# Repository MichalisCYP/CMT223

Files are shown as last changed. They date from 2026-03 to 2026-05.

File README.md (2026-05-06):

# FocusFlow: Distributed IoT Focus-Assist System

FocusFlow is a modular, distributed IoT system designed to enhance productivity using the Pomodoro technique, environmental monitoring, and computer vision. It features a Raspberry Pi "Fog Hub", an Arduino sensor node, and a modern web dashboard for real-time visualization and AI-powered session reporting.

---

## Key MVP Features

- **Session Management**: Automatic 25-minute focus and 5-minute break timers with start/pause/resume/stop controls via hardware buttons.
- **Environmental Monitoring**: Real-time tracking of light, sound, motion, temperature, and humidity.
- **Focus Estimation**: A heuristic-based focus score (0-100) calculated from environmental conditions.
- **Display Integration**: Grove-LCD (RGB) for environment data and Grove-OLED for session countdowns and focus scores.
- **Data Persistence**: Local SQLite database for offline-first reliability.
- **Cloud Synchronization**: Background publishing of telemetry and session events to AWS IoT Core.
- **Web Dashboard**: React/Vite-based interface with live status updates, historical charts, and AI-summarized focus reports.

---

## System Organisation & Data Flow

FocusFlow follows a "Fog Computing" architecture where data is processed locally at the edge for immediate feedback, while critical events are synced to the cloud for long-term analytics.

```mermaid
graph LR
    subgraph "Edge (Arduino)"
        A[Sensors] --> B[Arduino Firmware]
    end

    subgraph "Fog Hub (Raspberry Pi)"
        B -- "USB Serial (JSON)" --> C[Ingest Worker]
        C --> D[Shared State]
        E[Local Env Worker] --> D
        D --> F[Focus Worker]
        D --> G[Session Worker]
        F --> H[SQLite Repo]
        G --> H
        D --> I[Display Worker]
        I --> J[LCD / OLED]
    end

    subgraph "Vision Node (Raspberry Pi 2)"
        K[Camera] --> L[CV Processor]
    end

    subgraph "Cloud & Client"
        H -- "MQTT" --> M[AWS IoT Core]
        L -- "HTTPS/MQTT" --> M
        M -- "WebSockets" --> N[Web Dashboard]
        D -- "Local API" --> N
        O[Groq AI] -- "Analysis" --> N
    end
```

---

## Folder and File Structure

### Root Directory
- `arduino/`: Firmware for the Arduino-based sensor node.
- `raspberry/`: Core "Fog Node" implementation for the primary Raspberry Pi.
- `raspberry-2/`: Computer Vision (CV) processing node for the secondary Raspberry Pi.
- `FocusFlowDashboard/`: A React-based web dashboard for real-time visualization and analytics.
- `docs/`: Comprehensive project documentation following university SDLC standards.
- `iot-lab-book-master/`: Reference implementations and lab exercises used as a foundation.
- `requirements.txt`: Global Python dependencies.
- `SETUP.md`: (Deprecated) Integrated into this README.

### arduino/main/
The firmware responsible for local sensor polling and data transmission.
- `main.ino`: Primary entry point and setup/loop logic.
- `config.h`: Centralized pin definitions, thresholds, and timing constants.
- `environment_sensors.h`: Logic for reading Light, Sound, PIR, and DHT sensors.
- `payload_formatter.h`: Handles JSON serialization for data transmission to the Pi.
- `usbserial_transport.h`: Manages serial communication over USB.

### raspberry/
The "Brain" of the system, handling session logic, data persistence, and display updates.
- `main.py`: Entry point for the fog node.
- `fog/`: Core logic package containing multi-threaded workers for ingestion, session management, and focus calculation.
- `focusflow_mvp.db`: Local SQLite database storing telemetry and session events.

---

## Setup Instructions

### 1. Prerequisites
- **AWS Account**: Access to AWS IoT Core for cloud communication.
- **Python 3.9+**: Installed on both Raspberry Pi units.
- **Node.js 18+**: Installed for the Dashboard.
- **Arduino IDE**: For flashing the edge device firmware.
- **Hardware**: Arduino board, Raspberry Pi (Hub), Raspberry Pi (CV Node).

### 2. Hardware Wiring (Arduino)
Connect sensors to the specified pins as defined in `arduino/main/config.h`:
- **Light Sensor**: Analog Pin `A3`
- **Sound Sensor**: Analog Pin `A0`
- **PIR Motion Sensor**: Digital Pin `D2`
- **Button**: Digital Pin `D3` (Momentary, active LOW)
- **Ultrasonic Ranger**: Digital Pin `D7`
- **DHT Sensor**: Digital Pin `D4` (connected via GrovePi or directly)

### 3. Installation
#### Arduino Edge Device
1. Open `arduino/main/main.ino` in the Arduino IDE.
2. Install the **DHT sensor library** (by Adafruit) via the Library Manager.
3. Connect your Arduino and flash the code.

#### Raspberry Pi (Central Hub)
1. Navigate to `raspberry/` and install system dependencies:
   ```bash
   curl -kL https://get.pimoroni.com/grovepi | bash
   pip3 install -r requirements.txt
   ```
2. Run the initialization script:
   ```bash
   chmod +x start.sh && ./start.sh
   ```

#### FocusFlow Dashboard
1. Navigate to `FocusFlowDashboard/` and install dependencies:
   ```bash
   npm install
   ```

### 3. Configuration
- **AWS IoT**: Place your device certificates (`cert.pem`, `private.key`) in the `raspberry/` and `raspberry-2/` folders as appropriate.
- **Environment**: Copy `.env.example` to `.env` in the `FocusFlowDashboard/` directory and provide your `GROQ_API_KEY`.

---

## 🚀 Running the Project

### 1. Start the Hub & Edge
Plug the Arduino into the Central Pi via USB, then start the Fog service:
```bash
cd raspberry
python3 main.py
```

### 2. Start the CV Node
Run the vision script on the camera-equipped Pi:
```bash
cd raspberry-2
python3 basicCV.py --headless --hub-url http://<HUB_IP>:8787/api/peer-ingest
```

### 3. Start the Dashboard
Launch both the Vite frontend and Express backend:
```bash
cd FocusFlowDashboard
npm run dev:all
```
Access the UI at `http://localhost:5173`.

---

## Telemetry & Communication

### Arduino → Hub (JSON over Serial)
The Arduino node sends telemetry every 1 second in the following format:
```json
{ "v": 1, "light": 412, "sound": 275, "move": 1, "button": 0 }
```
It also sends discrete events for button interactions:
```json
{"v": 1, "btn_event": "SHORT"}
{"v": 1, "btn_event": "LONG"}
```

### Hub → Cloud (MQTT)
The Hub publishes data to AWS IoT Core on the following topics:
- `focusflow/environment`: Real-time sensor readings.
- `focusflow/session`: Session state changes (started, paused, stopped).
- `focusflow/focus`: Calculated focus scores and reason codes.

---

## Third-Party Software and Frameworks

| Software / Framework | Purpose | Documentation |
| :--- | :--- | :--- |
| **Arduino** | Hardware abstraction and sensor firmware platform | [arduino.cc](https://www.arduino.cc/) |
| **AWS IoT Core** | Managed cloud service for MQTT-based device sync | [aws.amazon.com/iot](https://aws.amazon.com/iot-core/) |
| **React** | Frontend library for the Dashboard UI | [react.dev](https://react.dev/) |
| **Vite** | Next-generation frontend tooling and dev server | [vitejs.dev](https://vitejs.dev/) |
| **Express** | Minimalist web framework for the backend API | [expressjs.com](https://expressjs.com/) |
| **OpenCV** | Open-source computer vision library | [opencv.org](https://opencv.org/) |
| **MediaPipe** | ML framework for face and gesture tracking | [mediapipe.dev](https://mediapipe.dev/) |
| **Groq** | High-speed AI inference for session reporting | [groq.com](https://groq.com/) |
| **SQLite** | Self-contained, serverless database engine | [sqlite.org](https://www.sqlite.org/) |

---

## Code Documentation

- **In-line Comments**: All Python and Arduino source files follow standard PEP8/Google style guides with descriptive comments.
- **Project Docs**: Detailed architectural designs, requirements, and implementation plans are located in the `docs/` directory.
- **Reference Lab Code**: This project builds upon concepts from the `iot-lab-book-master/` reference material:
    - **LAB 02**: DHT sensor reading patterns (used in `LocalEnvironmentWorker`).
    - **LAB 04/06**: MQTT cloud and Full Stack patterns (used in AWS Publisher).
    - **LAB 09**: Pi concurrency and worker orchestration (used in `fog/main.py`).

---

## Troubleshooting

- **Serial Device Errors**: If the Hub cannot connect to the Arduino, ensure the user has permissions for `/dev/ttyACM0` (`sudo usermod -a -G dialout $USER`).
- **Grove Hardware Not Found**: Verify that I2C is enabled in `raspi-config` and that the GrovePi board is correctly seated.
- **AWS Sync Failures**: Check that the system clock is synchronized (NTP) and that certificates are correctly named in `raspberry/main.py`.
- **Dashboard API Offline**: Ensure port `8787` is not blocked by a firewall and that `concurrently` is installed.

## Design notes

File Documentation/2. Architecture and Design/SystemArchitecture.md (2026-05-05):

# System Architecture

The FocusFlow system follows a tiered IoT architecture (Edge, Fog, Cloud) designed for real-time focus monitoring and productivity enhancement.

## High-Level Diagram

```mermaid
%%{init: {"flowchart": {"defaultRenderer": "elk", "htmlLabels": true}}}%%
flowchart TB
    %% LAYOUT CONTROL
    subgraph EDGE["Edge Layer: Sensing & Biometrics"]
        direction LR
        subgraph ARD["Arduino Sensor Node"]
            direction TB
            MCU["Atmega328P"]
            S1["Grove Light A3"]
            S2["Grove Sound A0"]
            S3["Grove DHT D5"]
            S4["Grove PIR D2"]
            S5["Grove Ultrasonic D6"]
            A1["LED Buttons D3/D7"]
        end
        subgraph CV["Raspberry Pi CV Node"]
            direction TB
            CAM["CSI/USB Camera"]
            PROC["OpenCV/MediaPipe"]
            SEC1["MQTT/TLS"]
        end
    end

    subgraph FOG["Fog Layer: Local Intelligence & Hub"]
        direction LR
        HUB["Pi Hub Controller"]
        DB1[("SQLite")]
        ALGO["Focus Analysis Worker"]
        INGEST["ArduinoIngestWorker"]
        GROVE["GroveWorker"]
        SESSION["SessionWorker"]
        DIS["DisplayWorker"]
        PUB["AwsIotPublisherWorker"]
        RPC["RpcWorker"]
        LCD["Grove LCD I2C"]
        OLED["OLED Display I2C"]
    end

    subgraph CLOUD["Cloud Layer: Aggregation & Services"]
        direction LR
        IOT["AWS IoT Core"]
        API["Cloud Node API"]
        DB2[("Cloud Database")]
        ANL["Cloud Analytics"]
    end

    subgraph CLIENT["Client Layer: User Interface"]
        direction TB
        subgraph DASH["FocusFlow Dashboard"]
            direction TB
            VZN["Visualization Engine"]
            subgraph VIEWS["Interactive Views"]
                direction LR
                LIVE["Live Environment"]
                TRND["Productivity Trends"]
                HIST["Session History"]
            end
        end
    end

    %% CONNECTIONS
    S1 -- Analog --- MCU
    S2 -- Analog --- MCU
    S3 -- Digital --- MCU
    S4 -- Digital --- MCU
    S5 -- Digital --- MCU
    A1 -- GPIO --- MCU

    CAM -- Frames --> PROC
    PROC -- "Payload: {facePresent:bool, eyes_detected:bool...}" --> SEC1

    MCU -- "USB Serial / JSON (Payload: {light, sound, move, temp, hum, distance_cm, button, button2})" --> INGEST
    INGEST -- parsed environment data --> HUB
    HUB -- light, sound, distance, move, temperature --> ALGO
    HUB -- grove button input --> GROVE
    GROVE -- button events --> SESSION
    HUB -- button events --> SESSION
    HUB <--> DB1
    ALGO -. "Inference: focus_score, reasons" .-> DB1

    SESSION -- session state --> LCD
    SESSION -- session state --> OLED
    HUB -- state snapshot --> DIS
    DIS -- "Env Metrics & Focus Score" --> LCD
    DIS -- "Timer & Session State" --> OLED

    HUB -- state snapshot --> RPC
    RPC -- "REST API / HTTP" --> VZN
    API <-- "HTTPS / WebSockets" --> VZN
    API -. "Aggregates: session_history, trends" .-> VZN

    SEC1 -- "MQTT over TLS" --> IOT
    PUB -- "MQTT over TLS" --> IOT
    HUB -- sensor & session data --> PUB
    IOT --> API
    API --> DB2 & ANL
```

## 1. System Components

### Edge Layer

- **Arduino Sensor Node**: A microcontroller-based unit that handles environmental sensing and physical user interaction (buttons).
- **Raspberry Pi CV Node**: A dedicated computer vision unit that processes video streams locally to extract focus-related biometric signals.

### Fog Layer

- **Raspberry Pi Hub**: The "brain" of the local environment. It orchestrates data ingestion, runs the local session manager (Pomodoro logic), and computes the real-time **Focus Score**.
- **Local Storage (SQLite)**: Ensures "local-first" operation, allowing the system to function without an internet connection.

### Cloud Layer

- **AWS IoT Core**: Acts as the secure message broker for device-to-cloud communication.
- **Cloud Node Services**: Handles long-term persistence, cross-session analytics, and serves the user-facing API.

### Client Layer

- **FocusFlow Dashboard**: A modern web application for real-time monitoring, historical review, and system configuration.

---

## 2. Data Types & Collection

| Category | Data Points | Collection Method |
| :--- | :--- | :--- |
| **Environmental** | `light_level`, `sound_level`, `temp`, `humidity`, `movement`, `distance` | Periodic sampling (1Hz - 5Hz) via Arduino  |
| **Biometric** | `face_present`, `looking_away`, `head_pose`, `slouching` | Local CV inference on Pi (2s interval) |
| **Session** | `status` (running/paused), `phase` (work/break), `duration` | Event-driven state transitions in Fog Node |
| **Inference** | `focus_score` (0-100), `focus_reasons`, `confidence` | Computed every 5s by Fog Node workers |

---

## 3. Sensors and Actuators

### Sensors

- **Light Sensor (Grove)**: Measures ambient lighting quality.
- **Sound Sensor (Grove)**: Estimates environmental noise distractions.
- **DHT11 (Grove)**: Monitors room comfort (Temperature/Humidity).
- **PIR Motion (Grove)**: Detects physical presence/movement.
- **Ultrasonic Ranger (Grove)**: Monitors desk distance and posture.
- **Camera (Pi Camera/USB)**: Captures video for local biometric analysis.

### Actuators

- **LED Buttons**: Provide visual feedback for session status (e.g., Glowing during work).
- **Grove LCD (16x2)**: Displays real-time environment metrics (Temperature, Humidity) and the current **Focus Score**.
- **OLED Display (128x64)**: Shows the active **Pomodoro Timer** and current session state (Work/Break/Paused).

---

## 4. Network Protocols & Communication

- **USB Serial (JSON)**: Reliable, low-latency communication between Arduino and Pi Hub.
- **I2C**: High-speed serial bus for local displays (LCD/OLED).
- **MQTT over TLS (MQTTS)**: Industry-standard secure messaging for IoT-to-Cloud telemetry.
- **HTTPS (REST)**: Secure request-response for dashboard-to-cloud configuration.
- **WebSockets (WSS)**: Low-latency, full-duplex communication for real-time dashboard updates.

---

## 5. Data Analytics Processes

### Edge Analytics (Biometrics)

The CV Node uses **Haar Cascades** and **MediaPipe Face Mesh** to process raw video frames. It extracts high-level features (like head yaw/pitch) without sending images to the cloud, ensuring user privacy.

### Fog Analytics (Local Inference)

The Fog Hub runs a **Multi-Factor Scoring Engine** that combines:

1. Environmental noise/light stability.
2. User presence and posture.
3. CV-derived focus signals.
   The engine outputs a normalized **Focus Score (0-100)** used for local alerts and displays.

### Cloud Analytics (Insights)

The Cloud Node aggregates data over days and weeks to identify **Productivity Trends**, such as peak focus times and common distractors. These insights are served via REST APIs to the client dashboard.

### Dashboard Analytics (Visualization)

The FocusFlow Dashboard transforms raw and aggregated data into actionable insights:

1. **Real-time Environment**: Visualizes live telemetry (light, sound, focus score) using WebSockets for immediate feedback.
2. **Trend Analysis**: Utilizes charting libraries (e.g., Recharts) to plot historical trends, allowing users to visualize productivity over time.
3. **Session History**: Processes event-driven data to reconstruct past focus sessions, providing a detailed log of work-break cycles and performance.

---

## 6. Security and Privacy

- **Transport Security**: All network communication (MQTT, HTTPS, WebSockets) is encrypted using **TLS 1.2/1.3**.
- **Device Authentication**: Devices connect to AWS IoT Core using **X.509 Client Certificates**, ensuring only authorized hardware can send data.
- **Local-First Privacy**: CV processing is entirely local. No video or images are stored or transmitted; only anonymous metadata (e.g., `looking_away: true`) leaves the device.
- **Access Control**: The Web Dashboard requires **JWT-based authentication** to access user-specific productivity data.

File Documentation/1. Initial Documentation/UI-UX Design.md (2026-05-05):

# Dashboard UX

## MVP Screens

- Live session
- Session history
- Alerts panel (can live inside main page)

## Live Session (Priority)

Must show:

- session title and state
- timer + current phase
- focus score
- current sensor values
- presence/CV status
- latest alerts
- actions: start, pause, resume, finish, acknowledge

Suggested layout:

- top: timer + focus + state
- middle: sensor cards
- bottom: event feed + controls

## History

Show:

- past sessions
- average focus per session
- simple trend charts (focus/environment)
- break recommendations vs acknowledgements

## UX Rules

- readable at a glance
- no debug noise on main screen
- actionable alerts only
- keep demo path obvious

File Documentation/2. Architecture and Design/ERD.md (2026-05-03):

# Data Model And Storage

## Storage Rules

- SQLite on the hub is the source of truth.
- Write local first, sync later.
- Thread-safe operations using locks for concurrent access.

## Core Tables

- environment_log: raw sensor readings from the environment.
- session_event: session lifecycle and phase tracking events.
- focus_log: computed focus scores and analysis results.

## SQLite Schema

```sql
CREATE TABLE environment_log (
    id INTEGER PRIMARY KEY AUTOINCREMENT,
    ts TEXT NOT NULL,
    light INTEGER,
    sound INTEGER,
    move INTEGER,
    button INTEGER,
    temperature REAL,
    humidity REAL,
    distance_cm INTEGER
);

CREATE TABLE session_event (
    id INTEGER PRIMARY KEY AUTOINCREMENT,
    ts TEXT NOT NULL,
    status TEXT NOT NULL,
    phase TEXT NOT NULL,
    remaining_seconds INTEGER NOT NULL
);

CREATE TABLE focus_log (
    id INTEGER PRIMARY KEY AUTOINCREMENT,
    ts TEXT NOT NULL,
    score INTEGER NOT NULL,
    confidence TEXT NOT NULL,
    reason TEXT NOT NULL
);
```

## Relationships

- environment_log: independent periodic sensor readings.
- session_event: independent session state changes and phase tracking.
- focus_log: independent computed focus analysis results.

## ERD

```mermaid
erDiagram
    ENVIRONMENT_LOG {
        INTEGER id PK
        TEXT ts
        INTEGER light
        INTEGER sound
        INTEGER move
        INTEGER button
        REAL temperature
        REAL humidity
        INTEGER distance_cm
    }

    SESSION_EVENT {
        INTEGER id PK
        TEXT ts
        TEXT status
        TEXT phase
        INTEGER remaining_seconds
    }

    FOCUS_LOG {
        INTEGER id PK
        TEXT ts
        INTEGER score
        TEXT confidence
        TEXT reason
    }
```

## AWS DynamoDB (Computer Vision)

- Table name: `computer_vision`
- Partition key: `device_id` (String)
- Sort key: `timestamp` (String)

Attributes:

- `device_id` (String)
- `timestamp` (String)
- `confidence` (Number or String)
- `eyes_detected` (Number)
- `face_present` (Boolean)
- `head_pose` (String)
- `looking_away` (Boolean)
- `slouching` (Boolean)

Example DynamoDB item (JSON):

```json
{
  "device_id": "device-123",
  "timestamp": "2026-05-03T12:34:56Z",
  "confidence": 0.92,
  "eyes_detected": 2,
  "face_present": true,
  "head_pose": "forward",
  "looking_away": false,
  "slouching": false
}
```

Mermaid ERD addition:

```mermaid
erDiagram
    COMPUTER_VISION {
        TEXT device_id PK
        TEXT timestamp PK
        REAL confidence
        INTEGER eyes_detected
        BOOLEAN face_present
        TEXT head_pose
        BOOLEAN looking_away
        BOOLEAN slouching
    }
```

## Data Access Patterns

- `write_environment()`: Insert periodic sensor readings with full payload.
- `write_session_event()`: Insert session state and phase changes.
- `write_focus()`: Insert computed focus analysis results.
- `latest_environment()`: Retrieve most recent sensor reading.
- `latest_session_event()`: Retrieve most recent session state.
- `latest_focus()`: Retrieve most recent focus analysis.

## Retention Defaults

- environment_log: every 1-5 seconds (managed by application logic).
- session_event: key state transitions throughout session.
- focus_log: every 30 seconds (managed by application logic).

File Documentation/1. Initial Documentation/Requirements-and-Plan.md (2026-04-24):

# Smart IoT Desk Assistant: Unified Requirements and 2-Person Delivery Plan

Deadline: 07/05/2026

This file is the single source of truth for MVP scope, delivery, and ownership.

## 1. Goal

Build a local-first focus assistant that can run a full study session without internet while providing explainable focus feedback and gentle interventions.

## 2. Scope

### 2.1 In Scope (MVP)

- Arduino telemetry: light, sound, PIR motion, temperature/humidity, distance.
- Raspberry Pi hub: ingest data, run session logic, compute focus score, store in SQLite.
- CV signal integration: face presence and looking-away input.
- Dashboard: live status and session history.
- Alerts: buzzer/display prompts with manual acknowledge/override.
- Background sync to AWS IoT Core (non-blocking).

### 2.2 Out Of Scope (MVP)

- Polished mobile app.
- Trained custom ML models.
- Full cloud analytics platform.
- Multi-user profiles.
- Phone detection for enforcement workflows (can be revisited after MVP).

## 3. Functional Requirements

1. Environment Monitoring

- Read light, sound, movement, temperature/humidity, and distance/presence signals.

2. Focus Estimation

- Generate a focus score from available sensor and CV signals.
- Mark confidence when signals are missing.

3. Session Management

- Create, start, pause, resume, and finish sessions.
- Support Pomodoro-style focus and break periods.

4. Interventions

- Trigger buzzer/display prompts from rule thresholds.
- Support manual acknowledge and override.

5. Dashboard

- Show live metrics and active session state.
- Show session history and summary statistics.

6. Cloud Sync

- Persist locally first.
- Retry cloud sync in the background without affecting local flow.

## 4. Non-Functional Requirements

- Works offline for full local session behavior.
- Survives temporary USB serial, CV, or cloud failures.
- Near real-time local dashboard updates (polling every 2 seconds for MVP).
- Maintainable by a 2-person team and demonstrable by 07/05/2026.

## 5. Constraints

- Team size: 2 people.
- Hardware available: 2 Arduinos, 2 Raspberry Pis.
- Raspberry Pi CPU budget is tight when combining CV + messaging + backend.
- AWS IoT Core learning curve is a delivery risk.

## 6. Finalized MVP Decisions

| ID | Decision | Outcome | Rationale |
| ---- | --- | --- | --- |
| D-01 | Temp/humidity sensor location | Arduino edge node | Keep core environment telemetry in one constant edge payload |
| D-02 | Display module | Grove I2C display on Raspberry Pi hub | Easy integration with Raspberry Pi and clear local feedback  |
| D-03 | Button behavior | Single momentary button on Pi hub: short press acknowledge, long press pause/resume | Direct local interaction with fog session manager |
| D-04 | CV node scope | Face presence + looking-away only | Useful signal without over-scoping ML |
| D-05 | CV transport | Local HTTP POST | Fast integration and easy debugging |
| D-06 | Dashboard updates | HTTP polling every 2 seconds | Reliable for MVP without WebSocket complexity |
| D-07 | AWS scope | AWS IoT Core only for MVP | Reduces delivery risk |

## 7. Technical Baseline (Recommended)

| Layer | Recommended Technology | Rationale |
| --- | --- | --- |
| Edge and Hub | Python 3.11, paho-mqtt, OpenCV | Mature Raspberry Pi ecosystem |
| CV Node | MediaPipe Face Mesh (presence and looking-away signals) | Good speed and reliability for MVP |
| Messaging | Mosquitto MQTT broker (local telemetry) | Lightweight and low-latency |
| Backend | FastAPI + SQLite | Fast delivery with zero-config DB  |
| Dashboard | Web dashboard (React or simple server-rendered UI) | Mobile app is out of MVP scope |
| Cloud | AWS IoT Core | Matches MVP cloud boundary |

## 8. Working Assumptions

- The system must continue local session behavior during cloud outage.
- Missing CV data should degrade confidence but not stop scoring.
- One active session at a time is sufficient for MVP.
- Any stretch goals are only attempted after all success criteria in Section 12 are met.

## 9. Two-Person Team Split

Person A: Hardware, Firmware, and CV

- Arduino wiring, firmware, and stable telemetry payloads.
- Hub-side device integration for buzzer, display, button behavior.
- CV runtime setup and local signal posting (presence and looking-away).
- Sensor calibration and hardware troubleshooting.

Person B: Hub Backend, Data, Dashboard, and Cloud Sync

- FastAPI endpoints, session state machine, and focus logic integration.
- SQLite schema, data writes, and session/history queries.
- Live dashboard and session controls.
- Background sync queue to AWS IoT Core.

Shared ownership

- Focus score threshold tuning.
- End-to-end integration, testing, demo script, and final report.

## 10. Delivery Plan to 07/05/2026

Delivery order:

1. Local MVP first.
2. Add focus and interventions.
3. Add CV integration.
4. Add cloud sync last.

### Phase 1: Foundation and Local MVP (22/03-04/04)

Outcomes:

- Stable Arduino telemetry into hub.
- SQLite writes and basic API routes running.
- Session create/start/finish and active dashboard view.

Tasks:

- Lock pin map and payload format.
- Implement local DB schema and ingest pipeline.
- Build initial dashboard page for live readings.

### Phase 2: Focus and Interventions (05/04-18/04)

Outcomes:

- Heuristic focus score running end-to-end.
- Buzzer/display prompts with acknowledge and override.

Tasks:

- Implement scoring thresholds and confidence output.
- Wire button short press (ack) and long press (pause/resume).
- Show intervention events in dashboard timeline.

### Phase 3: CV Integration and Hardening (19/04-30/04)

Outcomes:

- CV node sends face presence and looking-away signals to hub.
- Focus engine consumes CV when available and degrades gracefully when missing.

Tasks:

- Set up CV runtime and post compact payloads via local HTTP POST.
- Tune score weights and CPU usage on Raspberry Pi.
- Validate dashboard responsiveness with 2-second polling.

### Phase 4: Cloud Sync, Testing, and Demo Freeze (01/05-07/05)

Outcomes:

- Background sync to AWS IoT Core without blocking local flow.
- Integration tests and demo checklist completed.
- Final report artifacts updated.

Tasks:

- Implement sync queue worker and retry/backoff behavior.
- Run offline, dropout, and recovery test scenarios.
- Freeze demo build and finalize documentation.

## 11. Milestones

| Date Target | Milestone |
| --- | --- |
| 28/03/2026  | Sensors publish telemetry and backend stores data |
| 04/04/2026  | Session state and live dashboard are operational |
| 12/04/2026  | Focus score and interventions run end-to-end |
| 24/04/2026  | CV signals integrated and reflected in score/confidence |
| 03/05/2026  | AWS IoT Core background sync validated |
| 07/05/2026  | Final demo-ready system and report handoff |

## 12. Success Criteria

1. One full local session runs end-to-end.
2. Data persists in SQLite.
3. Focus status is visible and explainable.
4. At least one intervention triggers correctly.
5. System still works with internet disabled.

## 13. Risks and Scope Controls

Primary risks:

- Pi performance bottlenecks under combined CV and telemetry load.
- Accuracy degradation under poor lighting or glasses.
- Privacy and ethics concerns for camera-based monitoring.

If schedule pressure increases, reduce scope in this order:

1. Keep only face presence CV signal, defer looking-away.
2. Defer cloud summaries and publish only key session events.
3. Replace any LLM summary logic with rule-based templates.

## 14. Academic and Reporting Requirements

- Cite at least two studies linking indoor environment quality to cognitive performance.
- Reference nudge theory and relevant HCI literature for intervention design.
- Include ethics section: consent, camera usage transparency, retention policy.
- Include system architecture diagram and measurable targets (for example alert latency and score responsiveness).

## 15. Change Control

If decisions or scope change, update this file and related architecture/testing documents in the same commit.

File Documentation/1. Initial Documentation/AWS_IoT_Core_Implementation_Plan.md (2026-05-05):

# AWS IoT Core Implementation Plan (FocusFlow)

## 1. Purpose

Implement a cloud node on AWS that receives locally stored data from the Raspberry Pi Fog node, then serves that data to:

- Dashboard (web)

This plan is aligned to the current project architecture and codebase, especially:

- `raspberry/fog/repository.py`
- `raspberry/fog/workers.py`
- `raspberry/fog/config.py`
- `docs/1. Requirements/Requirements-and-Plan.md`
- `docs/2. Architecture and Design/SystemArchitecture.md`

## 2. Current Local State (As-Is)

The Raspberry Pi Fog node already writes data to local SQLite using three tables:

- `environment_log`
- `session_event`
- `focus_log`

Workers already run in background threads for ingest, session state, focus scoring, and display. A cloud sync worker is not yet implemented in the current code.

## 3. Target AWS Architecture (MVP)

### 3.1 Data Flow

1. Fog node writes all data to SQLite first (local-first behavior).
2. New background sync worker reads unsynced rows and publishes to AWS IoT Core over MQTT/TLS.
3. AWS IoT Rules route messages to cloud storage.
4. Cloud API reads cloud storage and serves dashboard queries.

### 3.2 AWS Services

Required for MVP:

- AWS IoT Core (device connectivity, MQTT topics, rules)
- DynamoDB (operational query store for app reads)
- Lambda (rule transform and API handlers)
  -- API Gateway (HTTPS endpoints for dashboard)
- CloudWatch Logs (observability)
- IAM (least-privilege access)

Recommended:

- Amazon Timestream (time-series analytics, optional if DynamoDB-only is sufficient for MVP)
  -- Cognito (user auth for dashboard)

## 4. MQTT Topic and Payload Design

### 4.1 Topic Convention

Use environment-based topic prefix:

- `focusflow/{env}/{site_id}/{device_id}/environment`
- `focusflow/{env}/{site_id}/{device_id}/session`
- `focusflow/{env}/{site_id}/{device_id}/focus`
- `focusflow/{env}/{site_id}/{device_id}/heartbeat`
- `focusflow/{env}/{site_id}/{device_id}/ack` (optional)

Example:

- `focusflow/prod/lab-a/pi-hub-01/environment`

### 4.2 Message Envelope

Every published message should include:

```json
{
  "message_id": "uuid-v4",
  "event_type": "environment|session|focus",
  "occurred_at": "2026-04-21T12:00:00Z",
  "published_at": "2026-04-21T12:00:02Z",
  "device_id": "pi-hub-01",
  "site_id": "lab-a",
  "payload": {
    "...": "table-specific fields"
  }
}
```

Table mapping:

- `environment_log` -> `event_type=environment`
- `session_event` -> `event_type=session`
- `focus_log` -> `event_type=focus`

## 5. Raspberry Pi Changes Required

### 5.1 SQLite Schema Updates

Add sync metadata to support reliable retries:

Option A (recommended): dedicated queue table

```sql
CREATE TABLE IF NOT EXISTS cloud_sync_queue (
  id INTEGER PRIMARY KEY AUTOINCREMENT,
  source_table TEXT NOT NULL,
  source_row_id INTEGER NOT NULL,
  topic TEXT NOT NULL,
  payload_json TEXT NOT NULL,
  status TEXT NOT NULL DEFAULT 'pending',
  retry_count INTEGER NOT NULL DEFAULT 0,
  next_retry_at TEXT,
  last_error TEXT,
  created_at TEXT NOT NULL,
  updated_at TEXT NOT NULL,
  UNIQUE(source_table, source_row_id)
);
```

Option B: add `synced_at` column to each existing table (simpler but less flexible).

Use Option A for clearer retry/backoff and operational visibility.

### 5.2 Repository Layer

Extend `Repository` with methods such as:

- `enqueue_for_cloud(source_table, source_row_id, topic, payload_json)`
- `fetch_pending_batch(limit, now_iso)`
- `mark_synced(queue_id)`
- `mark_retry(queue_id, retry_count, next_retry_at, last_error)`

When writing `environment_log`, `session_event`, and `focus_log`, also enqueue a corresponding cloud message.

### 5.3 New Background Worker

Add `CloudSyncWorker` in `raspberry/fog/workers.py`:

Responsibilities:

- Maintain AWS IoT MQTT connection (TLS cert auth)
- Poll pending queue batch every N seconds
- Publish each message with QoS 1
- Mark success/failure in queue
- Apply exponential backoff with jitter
- Keep running even if internet drops

Backoff suggestion:

- `next_retry = min(base * (2 ^ retry_count), max_backoff) + jitter`
- base: 2s
- max_backoff: 300s

### 5.4 Configuration

Add to `FogConfig` in `raspberry/fog/config.py`:

- `aws_iot_endpoint`
- `aws_iot_port` (8883)
- `aws_iot_client_id`
- `aws_iot_topic_prefix`
- `aws_iot_cert_path`
- `aws_iot_key_path`
- `aws_iot_ca_path`
- `cloud_sync_batch_size` (for example 50)
- `cloud_sync_poll_seconds` (for example 2.0)
- `cloud_sync_enabled` (true/false)

### 5.5 Main Startup Wiring

In `raspberry/fog/main.py`, instantiate and start the new `CloudSyncWorker` with other workers.

Critical behavior:

- If cloud worker fails, local workers continue.
- Never block local session flow due to cloud issues.

## 6. AWS IoT Core Setup Steps (Colleague Checklist)

### 6.1 Device Provisioning

1. Create IoT Thing per Pi hub (for example `pi-hub-01`).
2. Create certificate and keys.
3. Attach IoT policy allowing publish only to project topics.
4. Download cert/key/CA and place securely on Pi.

Policy scope example:

- Allow `iot:Connect` for approved client ID.
- Allow `iot:Publish` to `focusflow/prod/*`.
- Deny wildcard subscribe if not needed.

### 6.2 Topic Rule Routing

Create AWS IoT Rules for each topic family:

- Rule 1: environment topic -> Lambda transform -> DynamoDB table
- Rule 2: session topic -> Lambda transform -> DynamoDB table
- Rule 3: focus topic -> Lambda transform -> DynamoDB table

Alternative: one generic rule with `event_type` branching in Lambda.

### 6.3 Cloud Data Model (DynamoDB)

Create table: `FocusFlowEvents`

- Partition key: `pk` = `SITE#{site_id}#DEVICE#{device_id}`
- Sort key: `sk` = `TS#{occurred_at}#TYPE#{event_type}#ID#{message_id}`
- GSI1 (optional): `event_type` + timestamp for cross-device dashboards

Store original payload and normalized fields for query efficiency.

### 6.4 API Layer for Dashboard

Use API Gateway + Lambda endpoints:

- `GET /api/live/latest?site_id=...&device_id=...`
- `GET /api/sessions/recent?site_id=...&device_id=...`
- `GET /api/focus/trend?site_id=...&device_id=...&from=...&to=...`

Dashboard should call API, not IoT MQTT directly (for MVP simplicity and security).

## 7. Security and Compliance

- Use X.509 cert auth for device-to-IoT Core.
- Rotate certificates per semester or release cycle.
- Restrict IoT policy to exact topic prefix and client ID.
- Keep private keys outside Git; load via filesystem permissions and environment variables.
- Enable CloudWatch alarms for repeated auth failures and publish failures.

## 8. Reliability Requirements

- Local-first guarantee: all writes succeed locally regardless of internet.
- At-least-once cloud delivery from queue (QoS 1 + retry).
- Idempotency via `message_id` in cloud ingestion Lambda.
- Queue growth monitoring to detect prolonged outage.

## 9. Implementation Sequence (Recommended)

### Phase A: Local Queue + Worker Skeleton (Pi only)

- Add `cloud_sync_queue` schema.
- Enqueue rows for all three event types.
- Add worker loop with mocked publish.
- Verify no impact on existing local behavior.

Deliverable: local queue drains to mock publisher.

### Phase B: IoT Core Connectivity

- Provision Thing/cert/policy.
- Connect from Pi and publish heartbeat topic.
- Add real publish path in worker.

Deliverable: messages visible in AWS IoT MQTT test client/CloudWatch logs.

### Phase C: Rule + Storage + API

- Deploy IoT Rule + Lambda + DynamoDB.
- Validate transformed records in DynamoDB.
- Expose API Gateway endpoints.

Deliverable: dashboard can fetch cloud data from API.

### Phase D: Hardening + Monitoring

- Add retries/backoff/jitter tuning.
- Add dead-letter path after max retries.
- Add CloudWatch dashboards/alarms.

Deliverable: stable operation through network outage and recovery test.

## 10. Test Plan

### 10.1 Edge and Queue Tests

- Verify each local table insert creates one queue row.
- Verify queue row marks `synced` on successful publish.
- Verify retry fields update on simulated publish failure.

### 10.2 Offline/Recovery Tests

- Disconnect internet for 15-30 minutes.
- Confirm local session still runs and data accumulates.
- Reconnect internet and confirm queued backlog drains.

### 10.3 Cloud Path Tests

- Publish test events for all event types.
- Confirm DynamoDB records created with correct keys.
- Confirm API returns expected latest and trend results.

## 11. Suggested Ownership Split (2-Person Team)

Person A (Pi/Fog):

- SQLite queue schema and repository methods
- CloudSyncWorker implementation and resilience behavior
- Device cert installation and Pi runtime configuration

Person B (AWS/Cloud API):

- IoT Core Thing/policy/rules
- Lambda ingestion + DynamoDB schema
- API Gateway endpoints for dashboard

Shared:

- Topic contract and payload versioning
- End-to-end tests and demo script

## 12. Definition of Done

Cloud node implementation is complete when:

1. Pi persists locally and publishes in background without blocking local logic.
2. AWS IoT Core receives all three event types.
3. Cloud storage has queryable records by site/device/time.
4. Dashboard API returns latest and historical metrics from cloud data.
5. Offline/recovery scenario passes with no data loss.
6. Security baseline (cert auth + restricted policy) is in place.

## 13. Practical Notes for This Repository

- Existing `raspberry/cloud.py` is a ThingsBoard example and should not be used as-is for AWS IoT Core production path.
- The target implementation should live in the `raspberry/fog` module set so it integrates with current worker orchestration.
- Keep all new AWS configuration values environment-driven to preserve portability between lab devices.

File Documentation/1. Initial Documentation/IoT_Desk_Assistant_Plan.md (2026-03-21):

**FocusFlow (Smart IoT Desk Assistant)**

Project Evaluation & 2-Person Implementation Plan

_March 2026_

Supporting planning document. Final MVP scope and delivery decisions are maintained in `../1. Requirements/Requirements-and-Plan.md`.

# 1. Project Evaluation

## 1.1 Concept & Originality

The Smart IoT Desk Assistant is a well-conceived, multi-disciplinary project that merges embedded hardware, computer vision, AI, and full-stack software into a single cohesive product. The combination of local Edge AI processing with tangible physical interaction is a thoughtful design choice that differentiates it from app-only productivity tools.

### Strengths

- Strong scientific grounding — environmental sensors (DHT22, light, loudness) align with established research on ambient intelligence and cognitive performance.
- Privacy-first architecture — on-device CV inference avoids cloud video streaming, a genuinely competitive advantage.
- Multimodal focus estimation (EAR + head pose + presence + phone detection) is more robust than any single-signal approach.
- Tangible HCI (OLED, buttons, potentiometer, LED bar) reduces cognitive load versus screen-only interfaces.
- Clear problem-to-feature mapping already documented in the Summary, demonstrating mature project thinking.

### Risks & Challenges to Address

- Raspberry Pi 4 CPU budget is tight when running YOLOv5 + MediaPipe + MQTT simultaneously — profiling and quantisation will be essential.
- Eye-tracking accuracy degrades with glasses, poor lighting, and off-angle camera placement; mitigation strategy needed.
- Phone detection via camera raises ethical/privacy concerns that the report must address explicitly.
- Scope is large for 2 people — the phased plan below prioritises a working MVP before advanced features.
- The web + mobile platform doubles frontend work; consider starting with web-only and adding mobile in Phase 3.

## 1.2 Technical Feasibility

The project is technically feasible within a 4-phase semester timeline, provided scope is managed carefully. The recommended tech stack below balances capability with development speed.

| Layer | Recommended Technology | Rationale |
| --- | --- | --- |
| **Edge (Pi)** | Python 3.11, OpenCV, MediaPipe, paho-mqtt | Mature Pi ecosystem; MediaPipe is GPU-optional |
| **CV / AI** | MediaPipe Face Mesh (EAR + head pose), YOLOv5n | Optimised for ARM; YOLOv5 nano fits Pi memory |
| **Messaging** | Mosquitto MQTT broker (local) | Lightweight, low-latency sensor telemetry |
| **Backend** | FastAPI (Python) + SQLite | Shares codebase knowledge with Pi; SQLite = zero-config |
| **Web Frontend**  | React + Recharts + Tailwind CSS | Fast dashboards; rich charting library |
| **Mobile (opt.)** | React Native (share web logic) | Code reuse; defer to Phase 3 |
| **AI Summaries**  | OpenAI API / local Ollama (Mistral 7B) | Flexible; Ollama keeps data local |

## 1.3 Academic & Report Recommendations

To strengthen the written report and literature review, ensure the following are addressed:

- Cite at least 2 studies linking IEQ (indoor environment quality) to cognitive performance to justify the sensor selection.
- Reference nudge theory (Thaler & Sunstein, 2008) and relevant HCI papers to validate the physical interaction design.
- Include an ethical considerations section covering camera-based monitoring, consent, and data retention.
- A system architecture diagram (block diagram showing Pi sensors → MQTT → backend → frontend) is essential for the System Design chapter.
- Quantify evaluation criteria: target Focus Score accuracy, latency thresholds (<200 ms alert), and user study sample size.

# 2. Team Roles & Responsibilities

## 2.1 Role Split

The project naturally divides into two complementary tracks. Both members share ownership of integration and the final report.

| **Person A — Hardware & Edge AI** | **Person B — Backend & Platform** |
| --- | --- |
| Raspberry Pi hardware assembly & wiring | Project repo, CI/CD pipeline, Git workflow |
| All sensor drivers (DHT22, light, loudness) | MQTT broker (Mosquitto) & message routing  |
| Computer vision pipeline (EAR, head pose, YOLO) | FastAPI backend + REST endpoints |
| Focus Score algorithm | Database design and queries |
| OLED display UI & physical controls | Web dashboard (React + Recharts) |
| MQTT publishing from Pi | Session scheduling & analytics UI |
| LED ambient feedback & alert system | AI session summaries & personalised plans  |

# 3. Phased Implementation Plan

## Phase 1 — Foundation (Weeks 1–3)

Goal: Both members have working local environments. Person A has sensors publishing data; Person B has a backend receiving it.

## Phase 2 — Core Features (Weeks 4–7)

Goal: Full focus monitoring pipeline running on the Pi and streaming to a basic web dashboard.

## Phase 3 — Intelligence & Platform (Weeks 8–10)

Goal: AI-powered insights, alerts, scheduling, and a polished frontend.

## Phase 4 — Integration, Testing & Report (Weeks 11–13)

Goal: End-to-end system validated with real users; report complete.

| Phase | Task | Person A (Hardware/CV) | Person B (Backend/Platform) |
| --- | --- | --- | --- |
| **Phase 1** | Hardware Setup: Raspberry Pi, sensor wiring | ✓ | |
| | Sensor drivers: DHT22, light, loudness | ✓ | |
| | Camera module setup & test | ✓ | |
| | OLED display driver & basic UI | ✓ | |
| | Buttons & potentiometer input handling | ✓ | |
| | Project repo, CI/CD, folder structure | | ✓ |
| | MQTT broker setup (Mosquitto) | | ✓ |
| | Backend scaffolding (FastAPI/Node) | | ✓ |
| | Database schema (SQLite/PostgreSQL) | | ✓ |
| **Phase 2** | Eye tracking & EAR (eye aspect ratio) algorithm | ✓ | |
| | Head pose estimation (MediaPipe) | ✓ | |
| | Presence detection (distance/PIR) | ✓ | |
| | Phone detection (YOLOv5 lightweight) | ✓ | |
| | Focus Score computation logic | ✓ | ✓ |
| | Pomodoro timer logic (device-side) | ✓ | |
| | REST API endpoints (sessions, env data) | | ✓ |
| | Web dashboard frontend (React/Vue) | | ✓ |
| | Mobile app scaffold (React Native/Flutter, post-MVP only) | | ✓ |
| **Phase 3** | AI session summary generation (LLM prompt) | ✓ | ✓ |
| | Personalised study plan logic | | ✓ |
| | Break recommendation algorithm | ✓ | |
| | Gentle alert system (LED + OLED nudges) | ✓ | |
| | Analytics dashboard (charts, trends) | | ✓ |
| | Session scheduling (web + mobile) | | ✓ |
| **Phase 4** | End-to-end integration testing | ✓ | ✓ |
| | Performance benchmarking (Pi CPU/latency) | ✓ | |
| | User study / evaluation | ✓ | ✓ |
| | Documentation & final report write-up | ✓ | ✓ |

# 4. Key Milestones & Communication

## 4.1 Suggested Milestones

| Week | Phase | Milestone |
| --- | --- | --- |
| **3**  | Phase 1 End | Sensors publishing MQTT; backend storing data; basic web page displaying live env readings |
| **5**  | Phase 2 Mid | EAR eye tracking + head pose running in real-time on Pi at >10 fps |
| **7**  | Phase 2 End | Full Focus Score computed and displayed live on OLED and web dashboard |
| **9**  | Phase 3 Mid | Pomodoro sessions schedulable via web; break alerts firing on device |
| **10** | Phase 3 End | AI summaries generated post-session; environmental trend charts live |
| **12** | Phase 4 Mid | User study completed (3–5 participants); data collected |
| **13** | Phase 4 End | Final report submitted; demo-ready system |

## 4.2 Collaboration Tips

- Use a shared Git repo (GitHub/GitLab) with feature branches and pull requests for all code.
- Define a clear MQTT topic schema early (e.g. `desk/sensors/env`, `desk/cv/focus`) so both can work independently.
- Use a shared Notion or Trello board to track tasks per phase and flag blockers early.
- Hold a brief weekly sync (30 min) to demo progress and re-align priorities.
- Person B should provide Person A with a mock backend endpoint in Week 1 so CV work is unblocked.

## 4.3 Scope Management Advice

If time pressure builds, apply these cuts in order:

- Drop phone detection (YOLOv5) — replace with a simple inactivity heuristic.
- Defer mobile app to a stretch goal; focus on a polished web dashboard instead.
- Simplify AI summaries to a rule-based template if LLM integration proves complex.
- Cap user study at 3 participants if recruitment is slow; document limitations in the report.

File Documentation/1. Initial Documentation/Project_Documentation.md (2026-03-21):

# Introduction -- Background

A smart IoT desk assistant powered by AI aiming to assist and empower
the work of students and professionals.

Expand on:

Focus tracking (discipline, retain focus, mention short-form video
content and other daily factors)

Increase attention span

Monitor Study conditions

Time management, Personalised study plans and pomodoro timers

# Literature Review

Ambient Intelligence & Productivity: Cite studies proving that indoor
environmental quality (temperature, humidity, noise) directly impacts
cognitive focus. This scientifically justifies why your desk needs a DHT
and loudness sensor, not just a timer.

Multimodal Sensor Fusion: Cite papers showing that relying on a single
sensor (like just a camera) is error-prone. Argue that fusing visual
data (facial landmarks/EAR) with acoustic and spatial data creates a
highly accurate, research-backed "Focus Score."

Contrast cloud computing vulnerabilities with your local Edge AI
approach. Use literature to prove that processing video locally on the
Raspberry Pi (and only publishing lightweight MQTT telemetry) is the
state-of-the-art method for protecting user privacy.

Tangible HCI & Behavioral Nudges: Cite "nudge theory" and
Human-Computer Interaction (HCI) research to defend your physical
buttons, rotary knob, and ambient LED bar. Prove that tactile, ambient
feedback reduces cognitive load compared to navigating a web app or
dealing with loud, intrusive alarms.

# Requirements

# Problem Statement -- Objectives

# Methodology

# System Design

# Implementation

# Testing

# Evaluation

# Conclusion

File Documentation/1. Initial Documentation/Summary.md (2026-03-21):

# Problems we want to solve

1.  Short attention span

2.  Digital distractions

3.  Poor time management

4.  Lack of structured productivity

5.  Inefficient study/work environments

6.  Burnout and mental fatigue

# Features we want to implement and which problem they solve

- Real-time study/work environment monitoring (5):
  - Sensors: light, loudness, temperature and humidity

- Focus estimation (1,2):
  - Eye tracking

  - Presence tracking

  - Phone detection (post-MVP)

  - Head pose (looking away detection and distance sensor)

  - Desk monitoring (post-MVP)

  - Inactivity monitoring

- Study Session Management (3,4,6):
  - Schedule study sessions

  - Pomodoro timer during sessions

  - Focus estimation during sessions

  - Break recommendation

- Feedback Intervention -- Physical Interaction (4,5)
  - Gentle alerts according to the above monitoring data

  - Physical feedback (OLED screens)

  - Physical interaction (buttons, potentiometer)

- Planning and Analytics Platform (web first, mobile post-MVP) (4)
  - Session scheduling

  - Session summaries

  - Environmental data

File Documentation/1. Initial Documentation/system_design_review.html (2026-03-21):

FF

# FocusFlow — System Design Review

Architecture Evaluation and Archived Alternative Proposal

v1.0 · March 2026

Status: Archived proposal for comparison only. Canonical MVP architecture is defined in SystemArchitecture.md and Requirements-and-Plan.md.

## Archived Alternative Architecture

Core principle: Separate concerns into distinct layers — sensing, edge inference, local coordination, cloud sync, and client. Add explicit bidirectional data flow so commands can reach hardware from the app.

■ Layer 1 — Sensor Node (Arduino + Grove Shield)

Light Sensorlux level

Sound Sensorambient noise

Temp/Humiditycomfort index

Movement PIRpresence detect

Ultrasonichead distance

Buttonsmanual triggers

Potentiometersensitivity/vol

LCD Displaylocal status

↳ Connects to Hub via USB Serial (UART) — reliable, low-latency, no TCP stack required

USB Serial / I²C

▼

■ Layer 2 — Edge Hub (Raspberry Pi 4/5)

Sensor Aggregatorparse serial data

Camera Module30fps capture

Focus EngineML inference

Session ManagerPomodoro state

OLED Controllerfeedback display

Alert Enginebuzzer / LED

SQLite Storeoffline buffer

Sync Daemonqueue + retry

BT Commander→ OpenClaw

↳ Focus Engine: MediaPipe (head pose + eye gaze) + YOLOv8-nano (phone detection) running locally — no cloud latency
↳ Sync Daemon: writes to SQLite first, queues upload with exponential backoff, marks uploaded rows
↳ WebSocket server on port 8080 — optional local command channel for post-MVP experiments

Bluetooth (SPP) → OpenClaw

MQTT over TLS + HTTPS via AWS IoT Core

Optional LAN WebSocket ↕ Mobile App (post-MVP)

▼ ▼ ▼

■ OpenClaw Node (RPi Zero 2W)

BT Receiverlisten commands

Motion Ctrlarm gestures

OLED Subclaw status

↳ Defined behaviors: wave on Pomodoro end, point at phone if detected

■ AWS IoT + Cloud Services

IoT Ingestmessages

Cloud APIclients

Cloud DBstorage

Sync Workerretry

Analyticsreports

Realtimeupdates

↳ Cloud realtime channel pushes session updates to subscribed clients

■ Client Apps

Session Plannerschedule / goals

Analyticsfocus trends

Environmentlive sensor view

Remote Ctrl→ Hub WS

↳ Connects to cloud APIs for data and can use optional LAN control in post-MVP experiments

FocusFlow System Design Review · Archived alternative · Generated March 2026 7 issues · 9 recommendations · 1 proposed architecture

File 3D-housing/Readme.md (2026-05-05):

# 3D Housing

Enclosure design for the FocusFlow project.

## 🚀 How to Run & Export

You can use either the desktop app or your web browser:

### Option 1: Web Browser (Fastest)
1. Open the [**Online OpenSCAD Playground**](https://ochafik.com/openscad2/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).
2. Click **Render** in the bottom toolbar.
3. Click **Export STL**.

### Option 2: Desktop App
1. Install **[OpenSCAD](https://openscad.org/)**.
2. Open `CMT223 Project Design.scad`.
3. Use these shortcuts:
   - **Preview**: `F5`
   - **Render**: `F6`
   - **Export STL**: `F7`

## 🛠 Printing Notes
- **Supports**: Required for the front display openings and top mesh.
- **Internal Sled**: To view the frame, uncomment `internal_sled();` at the bottom of the script.

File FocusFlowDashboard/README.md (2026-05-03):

# FocusFlow AI Agent + Tutor Chat

This folder now includes a local AI API server for:

- Receiving your friend's Raspberry Pi data over LAN (`/api/peer-ingest`)
- Generating a study session report with Groq (`/api/agent/report`)
- Running a mini tutoring buddy chat (`/api/agent/chat`)

## 1) Environment setup

```bash
cd raspberry2
cp .env.example .env
```

Edit `.env` and set:

- `GROQ_API_KEY` (required)
- `PEER_SHARED_TOKEN` (optional but recommended)

## 2) Install and run

```bash
npm install
npm run dev:all
```

- Frontend dashboard: `http://localhost:5173`
- Local AI API: `http://localhost:8787`

## 3) Friend Pi sender (LAN)

Use `server/peer_sender_example.py` on your friend's Pi:

1. Set `TARGET_API` to your Pi LAN IP, for example `http://192.168.1.50:8787/api/peer-ingest`
2. Set `PEER_TOKEN` to match your `.env` value
3. Run:

```bash
python3 server/peer_sender_example.py
```

## 4) Dashboard usage

In the Live Session view:

- Click **Generate AI Report** for a summary + recommendations
- Use **Mini Tutoring Buddy** chat for personalized study help

The AI uses combined context from:

- Camera/CV feed from your AWS endpoint
- Your local focus/session telemetry
- Your friend's LAN-ingested environment/audio updates

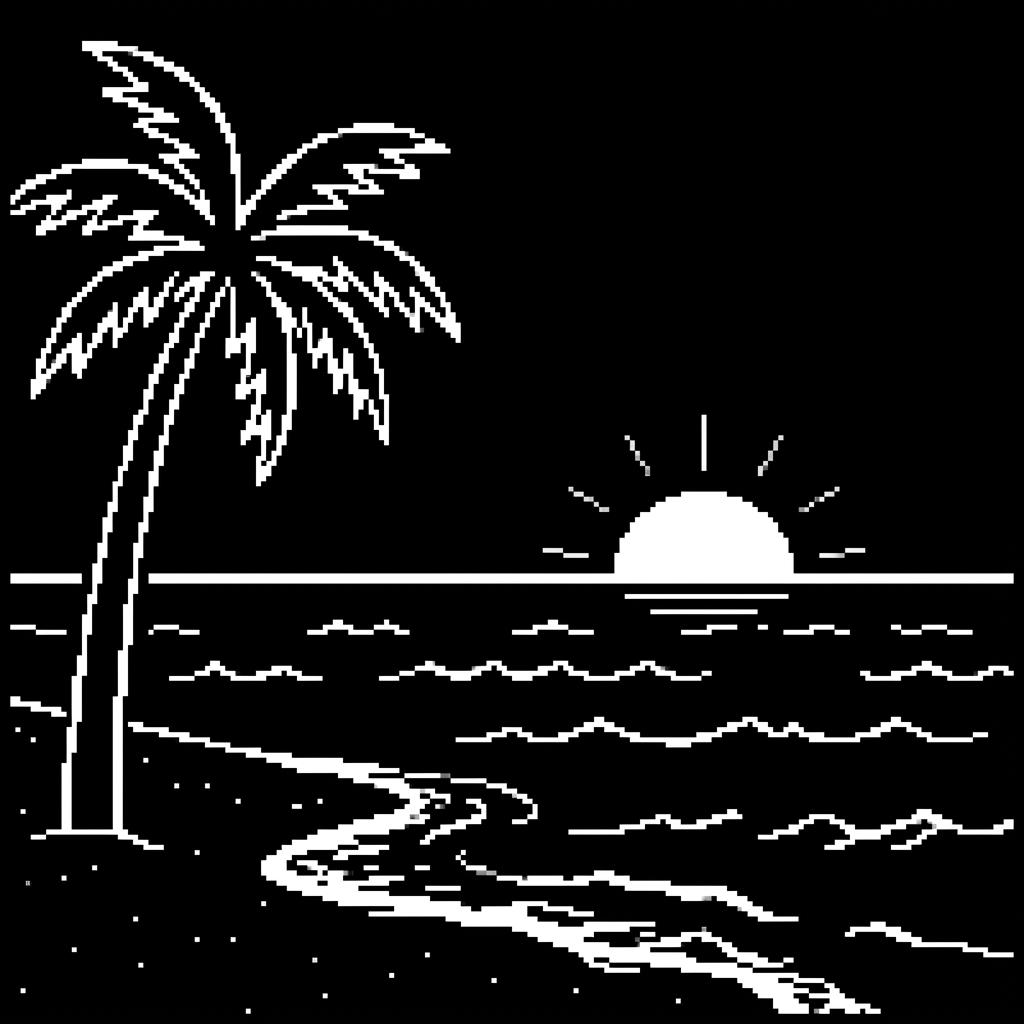
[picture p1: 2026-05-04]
raspberry/fog/assets/bg.png

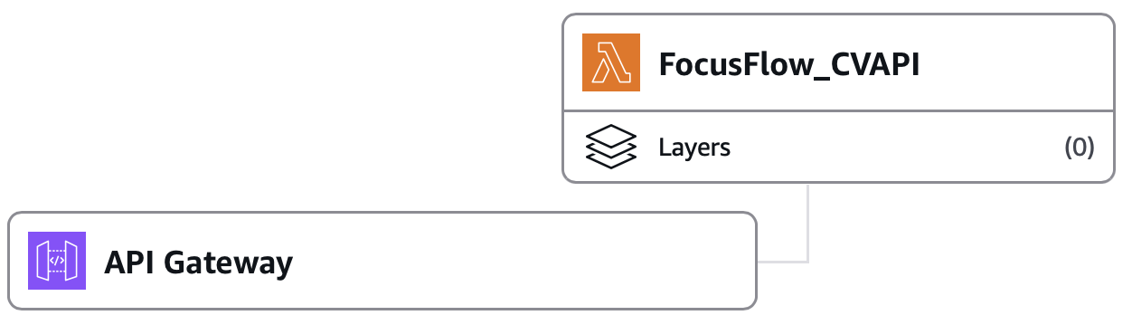
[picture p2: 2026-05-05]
AWS/api_gateway.png

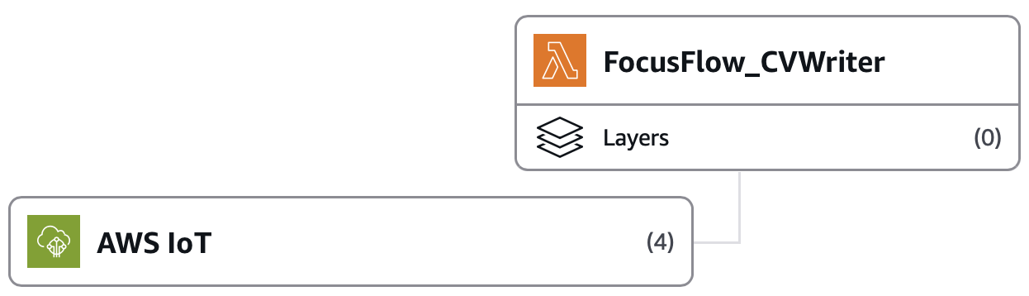
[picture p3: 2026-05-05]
AWS/AWS_IoT.png

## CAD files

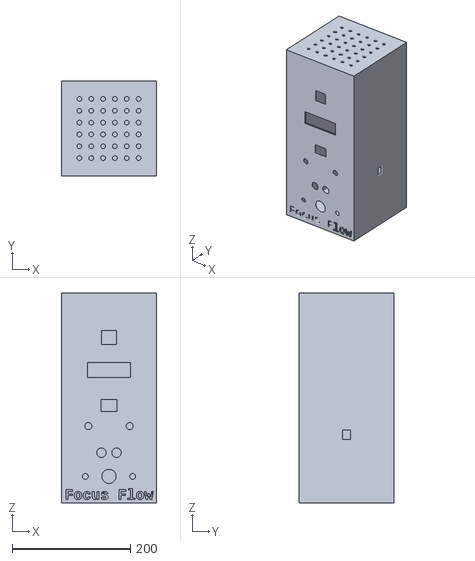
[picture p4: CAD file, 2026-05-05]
3D-housing/export.stl
160.0 x 160.0 x 355.0

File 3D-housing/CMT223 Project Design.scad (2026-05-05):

// FocusFlow Enclosure
// Got the exact dimensions off seedwiki so everything should snap in

w = 160;
d = 160;
h = 320;
pi_cover_h = 35; 
wall = 3;
tol = 0.5; // gap tolerance because the printer over-extrudes a bit

// component sizes
ribbon_w = 30;
ribbon_d = 4;
cam_w = 25;
cam_h = 24;
lcd_w = 72;
lcd_h = 25;
oled_w = 27;
oled_h = 20;
btn_r = 6;
us_r = 8;
us_spacing = 25.5;
pir_r = 12;
small_sensor_r = 5;
dht_w = 13;
dht_h = 16;
cable_hole_r = 15;

$fn = 60;

module main_body() {
    difference() {
        cube([w, d, h], center=true);
        cube([w - (wall*2), d - (wall*2), h - (wall*2)], center=true);
        
        // back panel opening
        translate([0, d/2, 0]) 
            cube([w - (wall*4), wall*4, h - (wall*4)], center=true);
            
        // top slit for the pi cam ribbon
        translate([0, -(d/2) + 20, h/2]) 
            cube([ribbon_w, ribbon_d, wall*4], center=true);
            
        // peg holes for the pi lid
        translate([(w/2)-10, (d/2)-10, h/2]) cylinder(h=wall*4, r=2.5, center=true);
        translate([-(w/2)+10, (d/2)-10, h/2]) cylinder(h=wall*4, r=2.5, center=true);
        translate([(w/2)-10, -(d/2)+10, h/2]) cylinder(h=wall*4, r=2.5, center=true);
        translate([-(w/2)+10, -(d/2)+10, h/2]) cylinder(h=wall*4, r=2.5, center=true);
            
        // cutting out the front face
        translate([0, -(d/2), 120]) cube([cam_w, wall*4, cam_h], center=true);
        translate([0, -(d/2), 65]) cube([lcd_w, wall*4, lcd_h], center=true);
        translate([0, -(d/2), 5]) cube([oled_w, wall*4, oled_h], center=true);
            
        translate([-35, -(d/2), -30]) rotate([90, 0, 0]) cylinder(h=wall*4, r=btn_r, center=true);
        translate([35, -(d/2), -30]) rotate([90, 0, 0]) cylinder(h=wall*4, r=btn_r, center=true);
            
        // ultrasonic eyes
        translate([-(us_spacing/2), -(d/2), -75]) rotate([90, 0, 0]) cylinder(h=wall*4, r=us_r, center=true);
        translate([(us_spacing/2), -(d/2), -75]) rotate([90, 0, 0]) cylinder(h=wall*4, r=us_r, center=true);
            
        // bottom row sensors
        translate([-40, -(d/2), -115]) rotate([90, 0, 0]) cylinder(h=wall*4, r=small_sensor_r, center=true);
        translate([0, -(d/2), -115]) rotate([90, 0, 0]) cylinder(h=wall*4, r=pir_r, center=true);
        translate([40, -(d/2), -115]) rotate([90, 0, 0]) cylinder(h=wall*4, r=small_sensor_r, center=true);
            
        // front engraving
        translate([0, -(d/2) + wall, -145]) 
            rotate([90, 0, 0]) 
            linear_extrude(wall*2) 
            text("Focus Flow", size=18, font="Arial:style=Bold", halign="center", valign="center");

        // dht sensor cutout on the right side
        translate([(w/2), 0, -45]) cube([wall*4, dht_w, dht_h], center=true);
    }
}

module back_door() {
    door_w = w - (wall*4) - tol;
    door_h = h - (wall*4) - tol;
    
    translate([0, (d/2) - (wall/2), 0]) {
        difference() {
            cube([door_w, wall, door_h], center=true);
            
            // power cable hole at the bottom
            translate([0, 0, -(door_h/2)]) 
                rotate([90, 0, 0]) cylinder(h=wall*4, r=cable_hole_r, center=true);
        }
    }
}

module pi_cover() {
    // container for the pi to sit on top
    translate([0, 0, (h/2) + (pi_cover_h/2)]) {
        difference() {
            cube([w, d, pi_cover_h], center=true);
            
            translate([0, 0, -wall])
                cube([w - (wall*2), d - (wall*2), pi_cover_h], center=true);
                
            // vents so it doesnt overheat during cv tasks
            for(vx = [-50 : 20 : 50]) {
                for(vy = [-50 : 20 : 50]) {
                    translate([vx, vy, pi_cover_h/2])
                        cylinder(h=wall*4, r=4, center=true);
                }
            }
            
            // cable routing out the back of the hat
            translate([0, (d/2), -(pi_cover_h/2) + 10])
                cube([40, wall*4, 20], center=true);
        }
        
        // pegs to snap it into the main body
        translate([(w/2)-10, (d/2)-10, -(pi_cover_h/2) - 2]) cylinder(h=4, r=2, center=true);
        translate([-(w/2)+10, (d/2)-10, -(pi_cover_h/2) - 2]) cylinder(h=4, r=2, center=true);
        translate([(w/2)-10, -(d/2)+10, -(pi_cover_h/2) - 2]) cylinder(h=4, r=2, center=true);
        translate([-(w/2)+10, -(d/2)+10, -(pi_cover_h/2) - 2]) cylinder(h=4, r=2, center=true);
    }
}

// comment out what you dont need to print right now
main_body();
back_door();
pi_cover();

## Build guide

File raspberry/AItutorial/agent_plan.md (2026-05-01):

LLM Agent Pipeline

1) Whisper.cpp to transcribe audio locally which is recorded through the usb headset connected to the raspberry pi.

2) Upon transcribing the audio, it is sent to the LLM via the Groq API. Along with the transcribed audio, a summary of the environment and the current session and environment is also sent to the LLM in the following format:
session_summary = "Session is currently {} with phase {} and {} seconds remaining."
environment_summary = "Current environment: light={}, sound={}, move={}, button={}"

3) Finally, the LLM processes the request, generates a response, sends it back to raspberry and that response is received and turned into audio using Vosk and played through the connected usb headset.

Main reference: https://github.com/brenpoly/be-more-agent (main implementation guide: agent_tutorial.py)

LLama.cpp, OpenWakeWord and Piper were going to be used but they are incompatible with the raspberry's 32-bit and therefore a cloud model was used, a button for waking the LLM and Vosk instead of piper.

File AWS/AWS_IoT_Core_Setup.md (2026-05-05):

# AWS IoT Core & Backend Setup Guide

This document outlines the configuration required for the FocusFlow AWS backend. The architecture consists of AWS IoT Core for message ingestion, Lambda functions for data processing and retrieval, DynamoDB for storage, and API Gateway for the dashboard interface.

## 1. DynamoDB Tables
Create four DynamoDB tables with the following schema:

| Table Name | Partition Key (String) | Sort Key (String) |
| :--- | :--- | :--- |
| `FocusFlow_CV` | `device_id` | `ts` |
| `FocusFlow_Environment` | `device_id` | `ts` |
| `FocusFlow_Session` | `device_id` | `ts` |
| `FocusFlow_Focus` | `device_id` | `ts` |

**Settings:**
- Capacity mode: **On-demand** (recommended for testing).
- Encryption: **Owned by Amazon DynamoDB**.

---

## 2. Lambda Functions

### A. Data Ingestion (Writer)
**Function Name:** `FocusFlow_CVWriter_Lambda`
- **Runtime:** Python 3.12+
- **Code:** [FocusFlow_CVWriter_Lambda.py](file:///Users/michaelkaramichalis/Developer/CMT223/AWS/FocusFlow_CVWriter_Lambda.py)
- **Role Permissions:** `dynamodb:PutItem` on all four tables.
- **Description:** Routes incoming MQTT messages to the appropriate DynamoDB table based on the topic or payload structure.

### B. Dashboard API (Reader)
**Function Name:** `FocusFlow_CVAPI_Lambda`
- **Runtime:** Python 3.12+
- **Code:** [FocusFlow_CVAPI_Lambda.py](file:///Users/michaelkaramichalis/Developer/CMT223/AWS/FocusFlow_CVAPI_Lambda.py)
- **Role Permissions:** `dynamodb:Query` on all four tables.
- **Description:** Provides REST endpoints for the FocusFlow Dashboard to fetch real-time and historical data.

---

## 3. AWS IoT Core Rules
Create a rule to trigger the `FocusFlow_CVWriter_Lambda` for all FocusFlow topics.

- **Rule Name:** `FocusFlow_Data_Routing`
- **SQL Statement:**
  ```sql
  SELECT *, topic() as topic FROM 'sdk/test/python'
  UNION ALL
  SELECT *, topic() as topic FROM 'focusflow/#'
  ```
- **Action:** Invoke Lambda function `FocusFlow_CVWriter_Lambda`.

---

## 4. API Gateway Setup
Expose the `FocusFlow_CVAPI_Lambda` via a REST API.

1. **Create REST API:** `FocusFlow_API`
2. **Create Resources & Methods:**
   - `/cv/latest` (GET)
   - `/cv/history` (GET)
   - `/env/latest` (GET)
   - `/env/history` (GET)
   - `/session/latest` (GET)
   - `/session/history` (GET)
   - `/focus/latest` (GET)
   - `/focus/history` (GET)
   - `/health` (GET)
3. **Integration:** Point all methods to `FocusFlow_CVAPI_Lambda` using **Lambda Proxy Integration**.
4. **CORS:** Enable CORS for all resources (required for the web dashboard).
5. **Deploy:** Create a stage (e.g., `prod`) and note the **Invoke URL**.

---

## 5. IAM Policy Template
Assign this policy to the execution roles of both Lambda functions (adjusting to `Query` or `PutItem` as needed for least privilege):

```json
{
    "Version": "2012-10-17",
    "Statement": [
        {
            "Effect": "Allow",
            "Action": [
                "dynamodb:PutItem",
                "dynamodb:Query",
                "dynamodb:GetItem"
            ],
            "Resource": [
                "arn:aws:dynamodb:*:*:table/FocusFlow_CV",
                "arn:aws:dynamodb:*:*:table/FocusFlow_Environment",
                "arn:aws:dynamodb:*:*:table/FocusFlow_Session",
                "arn:aws:dynamodb:*:*:table/FocusFlow_Focus"
            ]
        },
        {
            "Effect": "Allow",
            "Action": "logs:CreateLogGroup",
            "Resource": "arn:aws:logs:*:*:*"
        },
        {
            "Effect": "Allow",
            "Action": [
                "logs:CreateLogStream",
                "logs:PutLogEvents"
            ],
            "Resource": "arn:aws:logs:*:*:log-group:/aws/lambda/FocusFlow_*"
        }
    ]
}
```

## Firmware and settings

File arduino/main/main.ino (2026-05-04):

#include "usbserial_transport.h"
#include "config.h"
#include "environment_sensors.h"
#include "payload_formatter.h"
#include <DHT.h>

UsbSerialTransport transport;
DHT dht(config::PIN_DHT, config::DHT_TYPE);

unsigned long lastTelemetrySentAtMs = 0;
bool buttonState = false;
bool prevButtonState = false;
bool button2State = false;
bool prevButton2State = false;

void setup() {
  Serial.begin(config::SERIAL_BAUD);
  unsigned long serialWaitStartMs = millis();
  while (!Serial &&
         (millis() - serialWaitStartMs < config::SERIAL_WAIT_TIMEOUT_MS)) {
    ;
  }

  pinMode(config::PIN_PIR, INPUT);
  pinMode(config::PIN_LIGHT, INPUT);
  pinMode(config::PIN_SOUND, INPUT);
  pinMode(config::PIN_BUTTON, INPUT);
  pinMode(config::PIN_BUTTON2, INPUT);
  pinMode(config::PIN_DIST, INPUT);

  dht.begin();

  transport.begin(config::SERIAL_BAUD);
  transport.flush();
}

void loop() {
  const unsigned long nowMs = millis();
  buttonState = digitalRead(config::PIN_BUTTON);
  button2State = digitalRead(config::PIN_BUTTON2);

  if (buttonState != prevButtonState) {
    prevButtonState = buttonState;
  }

  if (button2State != prevButton2State) {
    prevButton2State = button2State;
  }

  if (nowMs - lastTelemetrySentAtMs >= config::TELEMETRY_INTERVAL_MS) {
    EnvironmentSample sample = readEnvironment(
        config::PIN_LIGHT, config::PIN_SOUND, config::PIN_PIR, dht,
      config::PIN_DIST, config::DISTANCE_TIMEOUT_US);
    String payload = formatTelemetryPayload(sample, buttonState, button2State);
    transport.writeLine(payload);
    lastTelemetrySentAtMs = nowMs;
  }

  delay(100);
}

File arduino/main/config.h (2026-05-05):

#ifndef CONFIG_H
#define CONFIG_H

#include <Arduino.h>

namespace config {

constexpr uint8_t PIN_PIR = 2;    // Grove PIR sensor signal
constexpr uint8_t PIN_LIGHT = A3;  // light sensor analog output
constexpr uint8_t PIN_SOUND = A0;  //sound sensor analog output
constexpr uint8_t PIN_BUTTON = 4;   // button signal
constexpr uint8_t PIN_BUTTON2 = 8;  // second button on D8
constexpr uint8_t PIN_DHT = 5;     // DHT sensor
constexpr uint8_t PIN_DIST = 6;    //ultrasonic ranger signal

constexpr unsigned long SERIAL_WAIT_TIMEOUT_MS = 3000;
constexpr unsigned long TELEMETRY_INTERVAL_MS = 2000;
constexpr unsigned long DISTANCE_TIMEOUT_US = 30000;

constexpr long SERIAL_BAUD = 9600;
constexpr uint8_t DHT_TYPE = 11;  // DHT11 module

}  // namespace config

#endif

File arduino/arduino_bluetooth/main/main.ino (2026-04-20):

#include "bluetooth_transport.h"
#include "button_handler.h"
#include "config.h"
#include "environment_sensors.h"
#include "payload_formatter.h"

UsbSerialTransport transport;
ButtonHandler button(config::PIN_BUTTON, true, config::BUTTON_DEBOUNCE_MS,
                     config::BUTTON_LONG_PRESS_MS);

unsigned long lastTelemetrySentAtMs = 0;

void setup() {
  Serial.begin(config::SERIAL_BAUD);
  unsigned long serialWaitStartMs = millis();
  while (!Serial &&
         (millis() - serialWaitStartMs < config::SERIAL_WAIT_TIMEOUT_MS)) {
    ;
  }

  pinMode(config::PIN_PIR, INPUT);
  pinMode(config::PIN_LIGHT, INPUT);
  pinMode(config::PIN_SOUND, INPUT);
  button.begin();

  transport.begin(config::SERIAL_BAUD);
  transport.flush();
}

void loop() {
  const unsigned long nowMs = millis();

  ButtonEvent event = button.update(nowMs);
  if (event == BUTTON_EVENT_SHORT) {
    String payload = formatButtonEventPayload("SHORT");
    transport.writeLine(payload);
  } else if (event == BUTTON_EVENT_LONG) {
    String payload = formatButtonEventPayload("LONG");
    transport.writeLine(payload);
  }

  if (nowMs - lastTelemetrySentAtMs >= config::TELEMETRY_INTERVAL_MS) {
    EnvironmentSample sample =
        readEnvironment(config::PIN_LIGHT, config::PIN_SOUND, config::PIN_PIR);
    String payload = formatTelemetryPayload(sample, button.isPressed());
    transport.writeLine(payload);
    lastTelemetrySentAtMs = nowMs;
  }

  delay(25);
}

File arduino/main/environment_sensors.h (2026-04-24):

#ifndef ENVIRONMENT_SENSORS_H
#define ENVIRONMENT_SENSORS_H

#include <Arduino.h>
#include <DHT.h>

struct EnvironmentSample {
  int light;
  int sound;
  int motion;
  float temperature;
  float humidity;
  int distanceCm;
};

inline int readGroveUltrasonicDistanceCm(uint8_t signalPin, unsigned long timeoutUs) {
  pinMode(signalPin, OUTPUT);
  digitalWrite(signalPin, LOW);
  delayMicroseconds(2);
  digitalWrite(signalPin, HIGH);
  delayMicroseconds(10);
  digitalWrite(signalPin, LOW);

  pinMode(signalPin, INPUT);
  const unsigned long durationUs = pulseIn(signalPin, HIGH, timeoutUs);
  if (durationUs == 0) {
    return -1;
  }

  return static_cast<int>(durationUs / 58UL);
}

inline EnvironmentSample readEnvironment(uint8_t lightPin, uint8_t soundPin,
                                         uint8_t pirPin, DHT& dht,
                                         uint8_t distancePin,
                                         unsigned long distanceTimeoutUs) {
  EnvironmentSample sample;
  sample.light = analogRead(lightPin);
  sample.sound = analogRead(soundPin);
  sample.motion = digitalRead(pirPin);
  sample.temperature = dht.readTemperature();
  sample.humidity = dht.readHumidity();
  sample.distanceCm = readGroveUltrasonicDistanceCm(distancePin, distanceTimeoutUs);

  if (isnan(sample.temperature)) {
    sample.temperature = 0.0f;
  }
  if (isnan(sample.humidity)) {
    sample.humidity = 0.0f;
  }

  return sample;
}

#endif

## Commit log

2026-03-13 arduino, raspberry, thingsboard
2026-03-13 arduino and cloud edits
2026-04-20 led debug
2026-04-20 led fix
2026-04-20 led fix2
2026-04-21 fixed LED
2026-04-21 Revert "Add AWS IoT Core background publisher worker for fog node"
    This reverts commit 8f46ba8c75627c6d198d7268fe46ab52850e12e5.
    [config.py, main.py, repository.py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]
2026-04-24 moved DHT, Distance to Arduino, moved Button to Pi, fixed display code SH1107
    [config.h, config.py, display.py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]
2026-04-24 port 1 i2c
2026-04-26 Comp Vision + button changes
2026-04-26 moved btn back to arduino due to fault on raspberry
2026-04-26 session working + OLED timer working
2026-05-03 led bar
2026-05-03 new button test
2026-05-04 session fix and history test
    [repository.py, session.py, workers.py]
2026-05-05 3d, initial diagrams
    [CMT223 Project Design.scad]
